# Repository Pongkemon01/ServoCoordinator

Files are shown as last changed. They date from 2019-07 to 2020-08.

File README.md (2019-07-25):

# Introduction 
TODO: Give a short introduction of your project. Let this section explain the objectives or the motivation behind this project. 

# Getting Started
TODO: Guide users through getting your code up and running on their own system. In this section you can talk about:
1.	Installation process
2.	Software dependencies
3.	Latest releases
4.	API references

# Build and Test
TODO: Describe and show how to build your code and run the tests. 

# Contribute
TODO: Explain how other users and developers can contribute to make your code better. 

If you want to learn more about creating good readme files then refer the following [guidelines](https://docs.microsoft.com/en-us/azure/devops/repos/git/create-a-readme?view=azure-devops). You can also seek inspiration from the below readme files:
- [ASP.NET Core](https://github.com/aspnet/Home)
- [Visual Studio Code](https://github.com/Microsoft/vscode)
- [Chakra Core](https://github.com/Microsoft/ChakraCore)

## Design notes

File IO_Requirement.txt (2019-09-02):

Note
===
Nuttx QEncoder module use TDTS = TCK_INT by leaving it as default (00).
Nuttx cannot operate in tickless mode because all required timers are used as encoder counters.
System clock configuration is in board.h as:
    - SYS_CLK         = 216MHz
    - USB_CLK         =  48MHz
    - APB1_CLK(PCLK1) =  54MHz (Timer1,8,9,10,11 operate at 108MHz (2x))
    - APB2_CLK(PCLK2) = 108MHz (Timer2,3,4,5,6,7,12,13,14 operate at 216MHz (2x))
STM32F7 has a dedicated timer all SysTick to periodically interrupt the system.  Nuttx uses this timer for system clock. (See stm32_timerisr.c)
SysTick input clock frequency is 27MHz (216MHz / 8).
The Nuttx default SysTick period is 10ms (100Hz). This value can be changed by defining CONFIG_USEC_PER_TICK in "defconfig" (undefined by default).
Starting additional drivers such as quadratic encoder must be manually include into "stm32_appinitialize.c".

Nuttx Kconfig modifications
===
The line 'default "coordinator" if ARCH_BOARD_COORDINATOR' must be add to configs/Kconfig.
The lines 
  if ARCH_BOARD_COORDINATOR
  source "configs/coordinator/Kconfig"
  endif
must be added to configs/Kconfig.
Also, the lines
   config ARCH_BOARD_COORDINATOR
        bool "PTTEP Coordinator(STM32F767ZI)"
        depends on ARCH_CHIP_STM32F767ZI
        select ARCH_HAVE_LEDS
        select ARCH_HAVE_BUTTONS
        select ARCH_HAVE_IRQBUTTONS
        ---help---
                This is the coordinator board for PTTEP project. It is based on
                STM32F767ZI built as Nucleo-144 board.
must be added to configs/Kconfig.

I/O requirement (Total 31 inputs and 42 outputs = 75 GPIOs)
===
Encoder+Home : 3-bit input per motor. Total 12+6 inputs.
Pulse+Direction : 2-bit output per motor. Total 12 outputs.
Control signal : 3-bit output (Servo_on, Alarm_reset, Deviation_clr) and 2-bit input (Alarm_status, Positioning_complete). Total 18 outputs + 12 inputs.
Emergency stop : 1-bit input
Status LED (Bi-color) : 2-bit output per LED. 1 LED per 1 motor. Total 12 outputs.
I2C for extension (Optional) : SCL SDA

I/O assignment (79 GPIO pins available)
===
CAUTION!!!: SB13 must be desoldered for PA1 (used by Ethernet) to be available
            JP7 must be removed to detached PB13 from Ethernet TXD
Optional: As Ethernet module is disabled, these SB can be desolderd to release some more IO pins:
    SB164 (PC1), SB160 (PA2), SB178 (PC4), SB181 (PC5), SB182 (PG13), SB183 (PG11)

- Fixed assignments
  ===
Encoders: PA0, PA1, PA15, PB3, PB4, PB5, PC6, PC7, PD12, PD13, PE9, PE11
  Enc0: GPIO_TIM1_CH1IN_2 (PE9) + GPIO_TIM1_CH2IN_2 (PE11)
  Enc1: GPIO_TIM2_CH1IN_2 (PA15) + GPIO_TIM2_CH2IN_2 (PB3)
  Enc2: GPIO_TIM3_CH1IN_2 (PB4) + GPIO_TIM3_CH2IN_2 (PB5)
  Enc3: GPIO_TIM4_CH1IN_2 (PD12) + GPIO_TIM4_CH2IN_2 (PD13)
  Enc4: GPIO_TIM5_CH1IN_1 (PA0) + GPIO_TIM5_CH2IN_1 (PA1)  (PA1 is not available on Zio connector. Must be wired to Morpho connector)
  Enc5: GPIO_TIM8_CH1IN_1 (PC6) + GPIO_TIM8_CH2IN_1 (PC7)

Motor pluse: PA6, PB8, PB9, PB15, PE5, PF9
  Motor0(Timer9): GPIO_TIM9_CH1OUT_2 (PE5)
  Motor1(Timer10): GPIO_TIM10_CH1OUT_1 (PB8)
  Motor2(Timer11): GPIO_TIM11_CH1OUT_1 (PB9)
  Motor3(Timer12): GPIO_TIM12_CH2OUT_1 (PB15) (Channel 1 out is not available on Nucleo-144. Thus, channel 2 is used.)
  Motor4(Timer13): GPIO_TIM13_CH1OUT_1 (PA6)
  Motor5(Timer14): GPIO_TIM14_CH1OUT_2 (PF9)

I2C(module 2)(Optional) : SCL=PB10, SDA=PB11
PA4(in), PA5(in) : Available for external interrupt pins

- Free assignments
  ===
  PA (3 pins) : 3, 4, 5
  PB (4 pins) : 0, 1, 2, 6, 12, 13 (JP7 must be removed)
  PC (8 pins) : 0, 2, 3, 8, 9, 10, 11, 12
  PD (13 pins): 0, 1, 2, 3, 4, 5, 6, 7, 11, 14, 15
  PE (12 pins): 0, 2, 3, 4, 6, 7, 8, 10, 12, 13, 14, 15
  PF (14 pins): 0, 1, 2, 3, 4, 5, 7, 8, 10, 12, 13, 14, 15
  PG (6 pins) : 0, 1, 2, 3, 9, 14

Emergency button : PA3
Home : PG0, PG1, PG2, PG3, PG9, PG14 (All PG)
Control signal (input){alrm_stat+pos_cmplt}: {PE0+PE8}, {PE2+PE10}, {PE3+PE12}, {PE4+PE13}, {PE6+PE14}, {PE7+PE15} (ALL PE)

Control signal (output){sv_on+alrm_res+dev_clr} : {PF0+PB0+PF7}, {PF1+PB1+PF8}, {PF2+PB2+PF10}, {PF3+PB6+PF12}, {PF4+PB12+PF13}, {PF5+PB13+PF14} (PB+PF)
Status LED : PD0, PD1, PD2, PD3, PD4, PD5, PD6, PD7, PD11, PD14, PD15, PF15
Direction : PC0, PC2, PC3, PC8, PC9, PC10

Pin direction
===
PA : Input
PB : Output
PC : Output
PD : Output
PE : Input
PF : Output
PG : Input

Unused I/O
===
PC11, PC12 (out)

Special function on GPIO after reset
===
The debug pins are in AF pull-up/pull-down after reset (Be careful):
PA15: JTDI in pull-up (input)
PB4: NJTRST in pull-up (input)
PB3: JTDO in floating state (output)

The following is CubeMX code to release PB3 and PB4 but it is better to avoid using these pins (especially PB3)
static void MX_GPIO_Init(void)
{
    GPIO_InitTypeDef GPIO_InitStruct;
    /* GPIO Ports Clock Enable */
    __HAL_RCC_GPIOB_CLK_ENABLE();
    __HAL_RCC_GPIOA_CLK_ENABLE();
    /*Configure GPIO pin Output Level */
    HAL_GPIO_WritePin(GPIOB, GPIO_PIN_4|GPIO_PIN_3, GPIO_PIN_RESET);
    /*Configure GPIO pins : PB4 PB3 */
    GPIO_InitStruct.Pin = GPIO_PIN_4|GPIO_PIN_3;
    GPIO_InitStruct.Mode = GPIO_MODE_OUTPUT_PP;
    GPIO_InitStruct.Pull = GPIO_NOPULL;
    GPIO_InitStruct.Speed = GPIO_SPEED_FREQ_LOW;
    HAL_GPIO_Init(GPIOB, &GPIO_InitStruct);
}

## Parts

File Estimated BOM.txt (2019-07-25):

Mouser
===
511-NUCLEO-F767ZI (Nucleo)	@THB731.40 x 1
SNO							@THB1558.20
SNOMkr						@THB922.20
ICM-20600(Mems+Gyro)		@THB103.67 x 1
TLP293-4					@THB40.0 x 10
DS26LV31TMX					@THB56.92 x 5
AM26LV32CDR					@THB43.25 x 5
IN-S85DATRG(LED)			@THB15.58 x 12
617-09663116501 (25pin con)	@THB193.98 x 6
538-39773-0002 (2pin con)	@THB35.30 x 10
CRCW08054K70FKEAC(R4.7k)	@THB0.731 x 100
CRCW0805330RFKEAC(R330)		@THB1.46 x 20
710-61302011121(pin header)	@THB31.01 x 10
437-8018300610001101(pin socket) @THB23.69 x 20

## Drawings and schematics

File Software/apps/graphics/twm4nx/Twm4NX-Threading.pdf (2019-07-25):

### Twm4x Main Thread

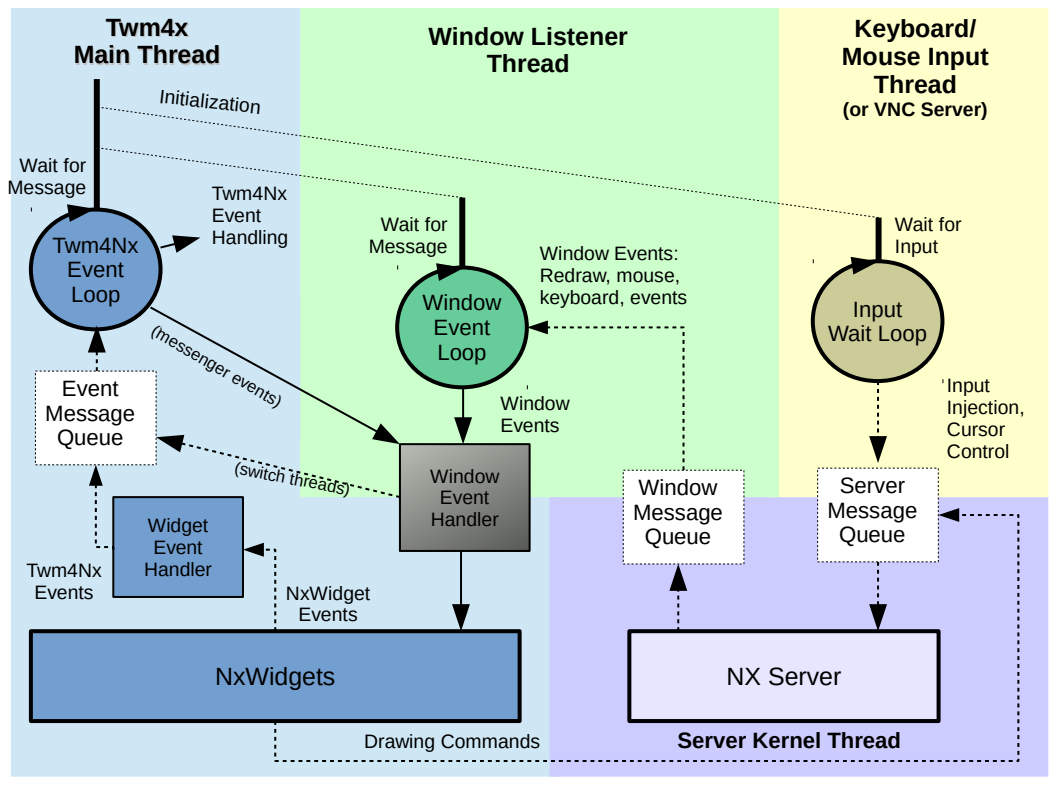
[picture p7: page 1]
Widget Event Handler; Twm4Nx Event Loop; Twm4Nx Event Handling; Initialization; Window Event Loop; Window Listener Thread; Input Wait Loop; Server Message Queue; Window Message Queue; Event Message Queue; NxWidgets; NX Server; Input Injection, Cursor Control; Window Events: Redraw, mouse, keyboard, events; Window Events; Drawing Commands; (switch threads); (messenger events); NxWidget Events; Twm4Nx Events; Window Event Handler; Wait for Input; Wait for Message

Keyboard/
Mouse Input
Thread
(or VNC Server)

Server Kernel Thread

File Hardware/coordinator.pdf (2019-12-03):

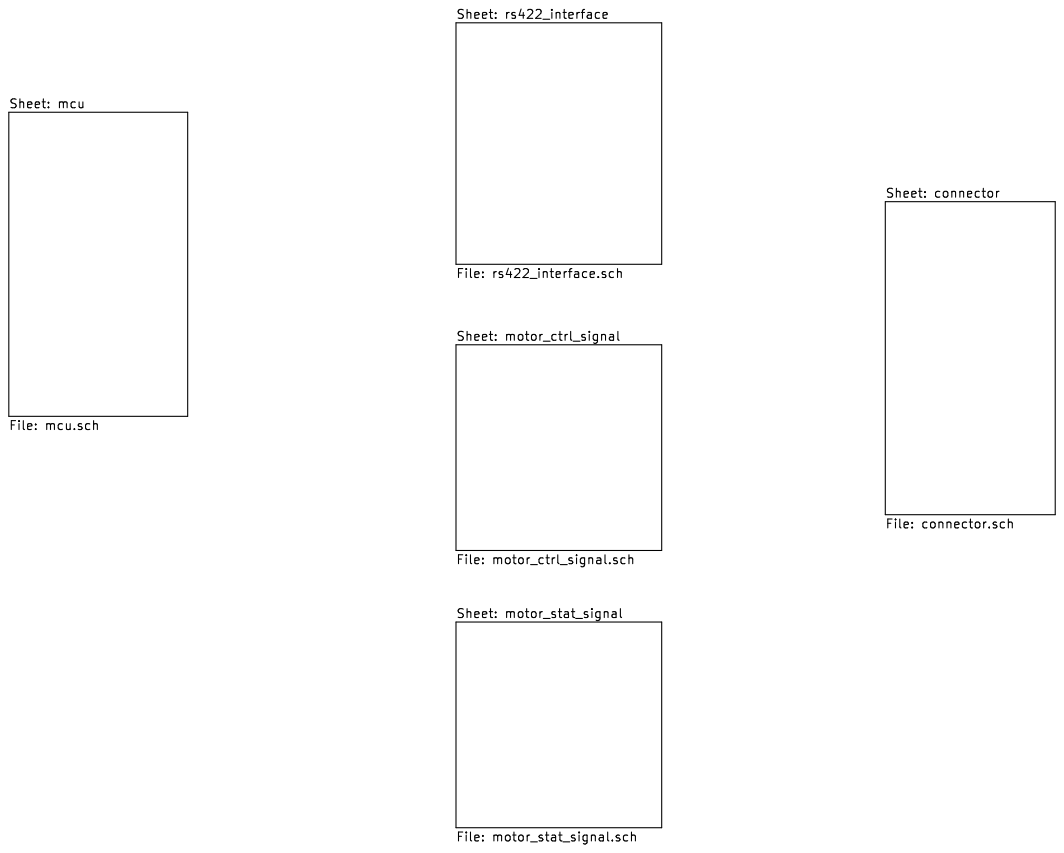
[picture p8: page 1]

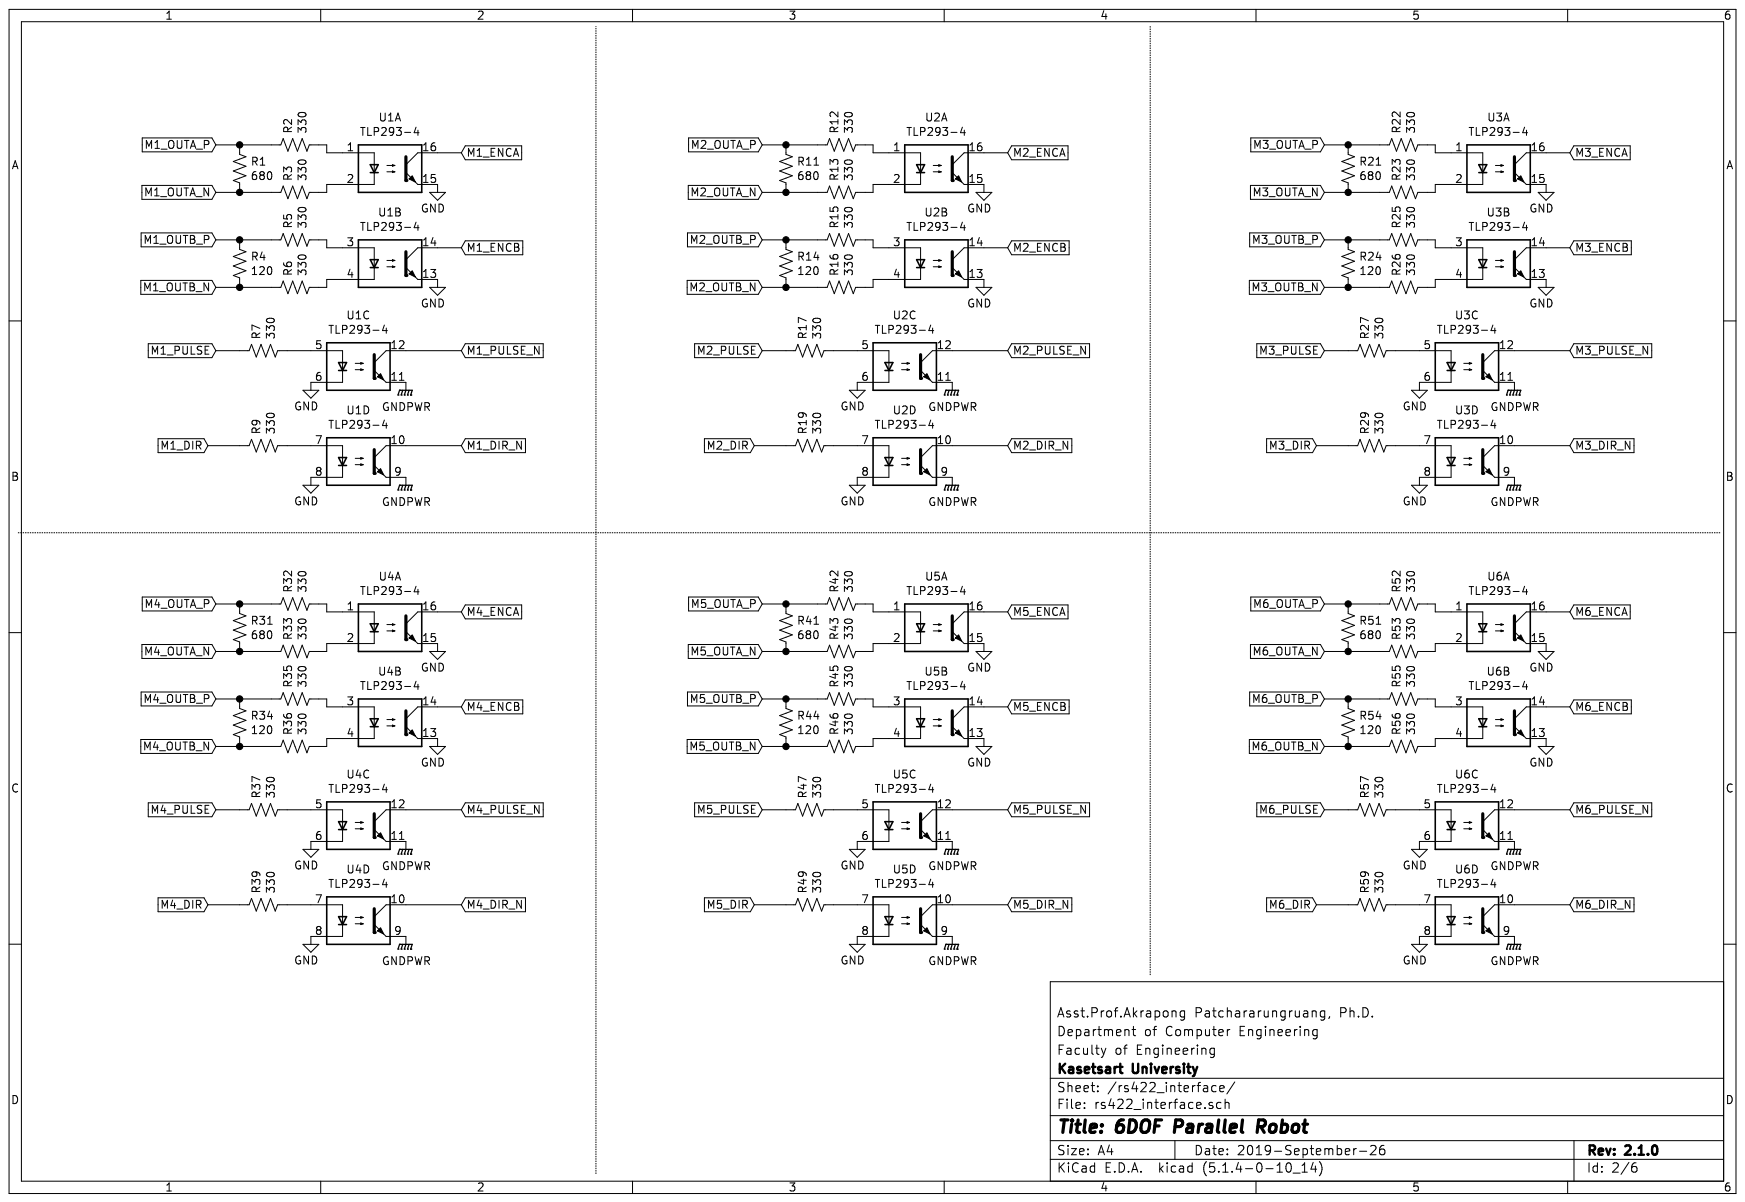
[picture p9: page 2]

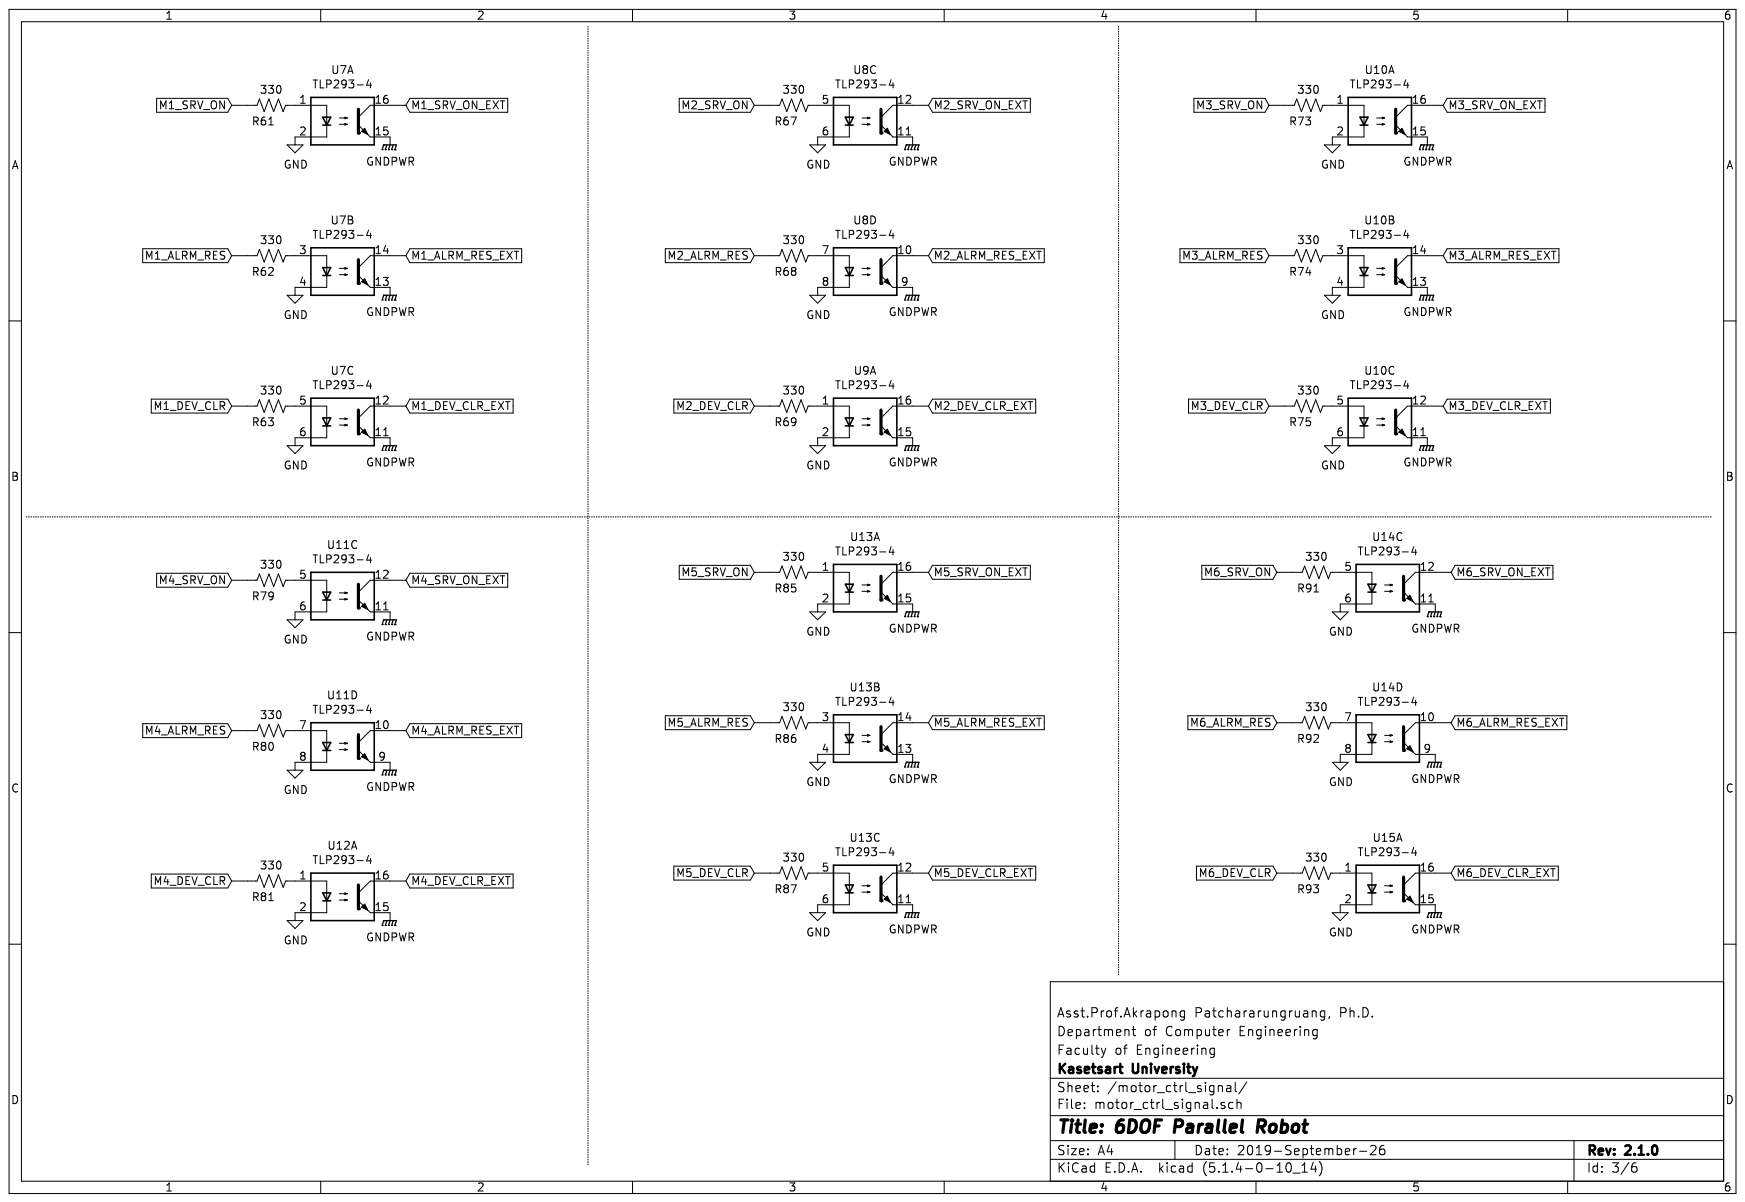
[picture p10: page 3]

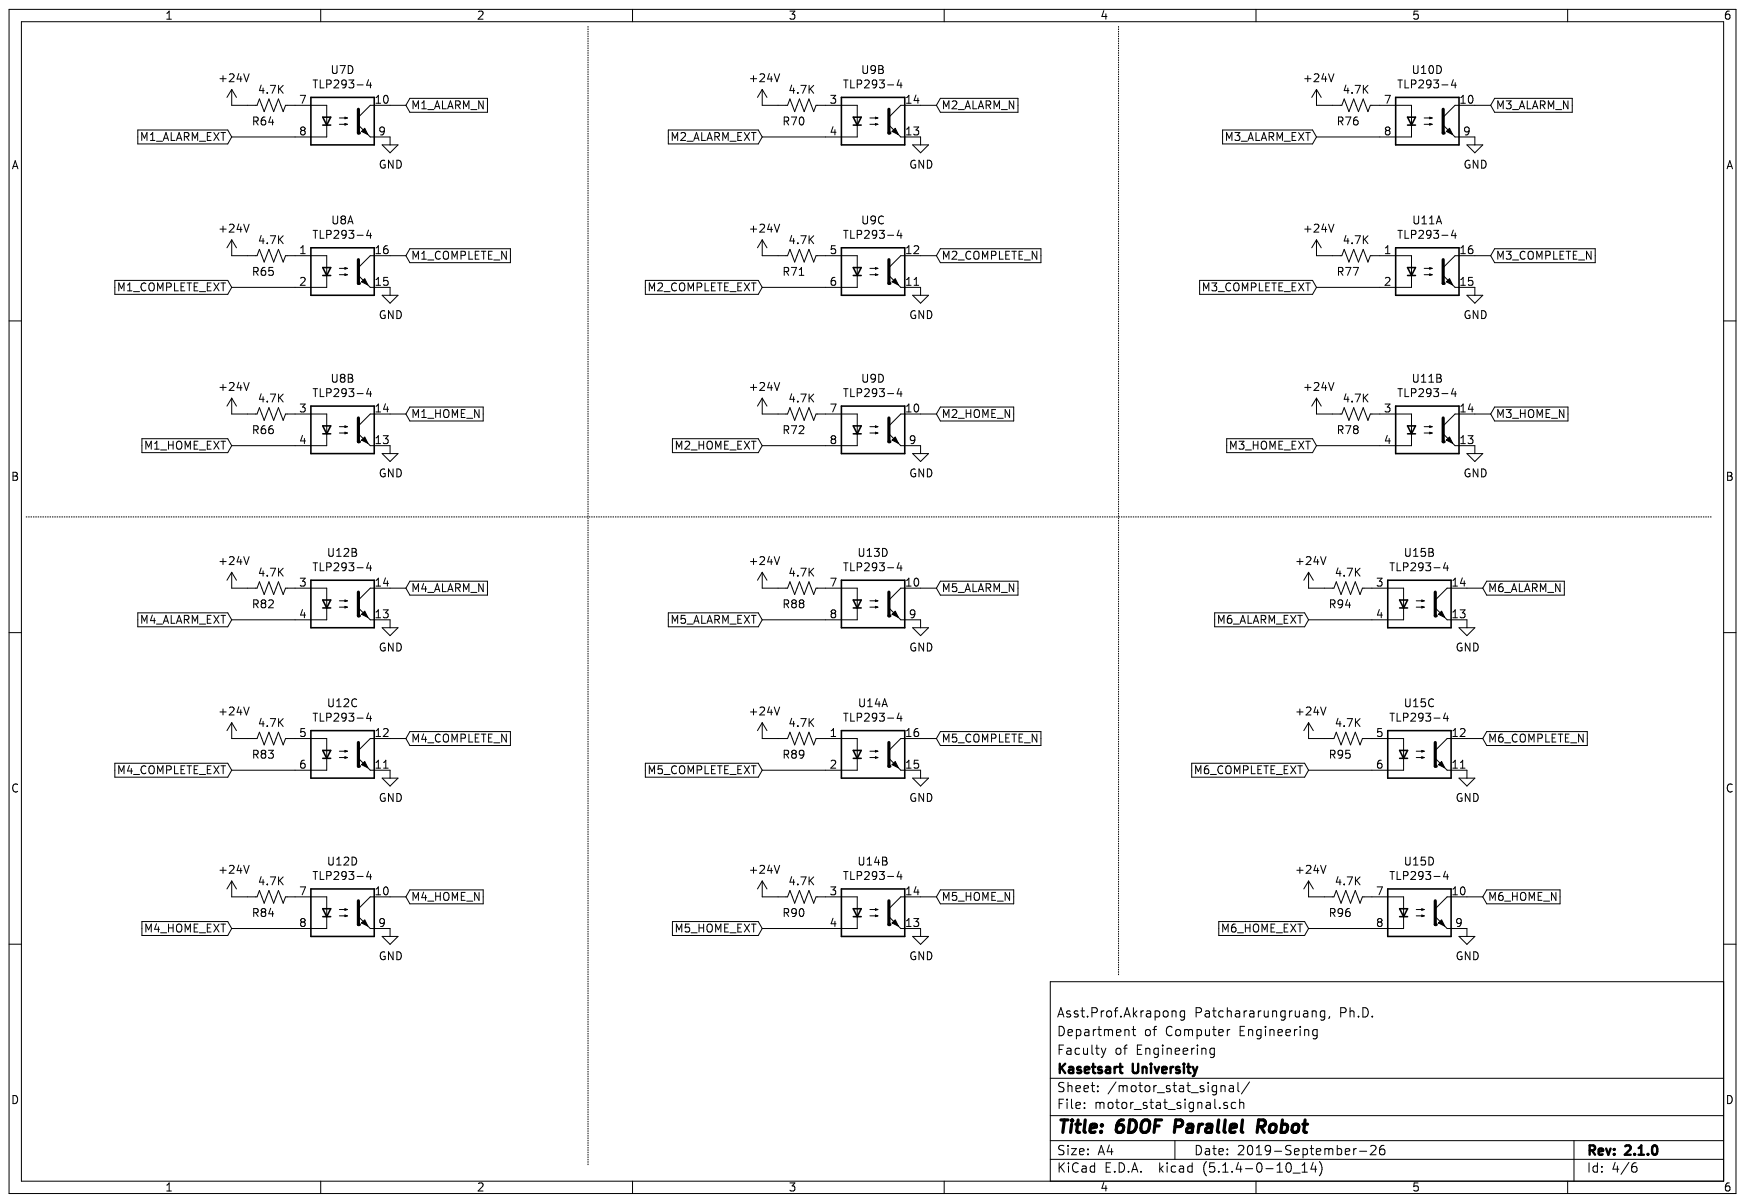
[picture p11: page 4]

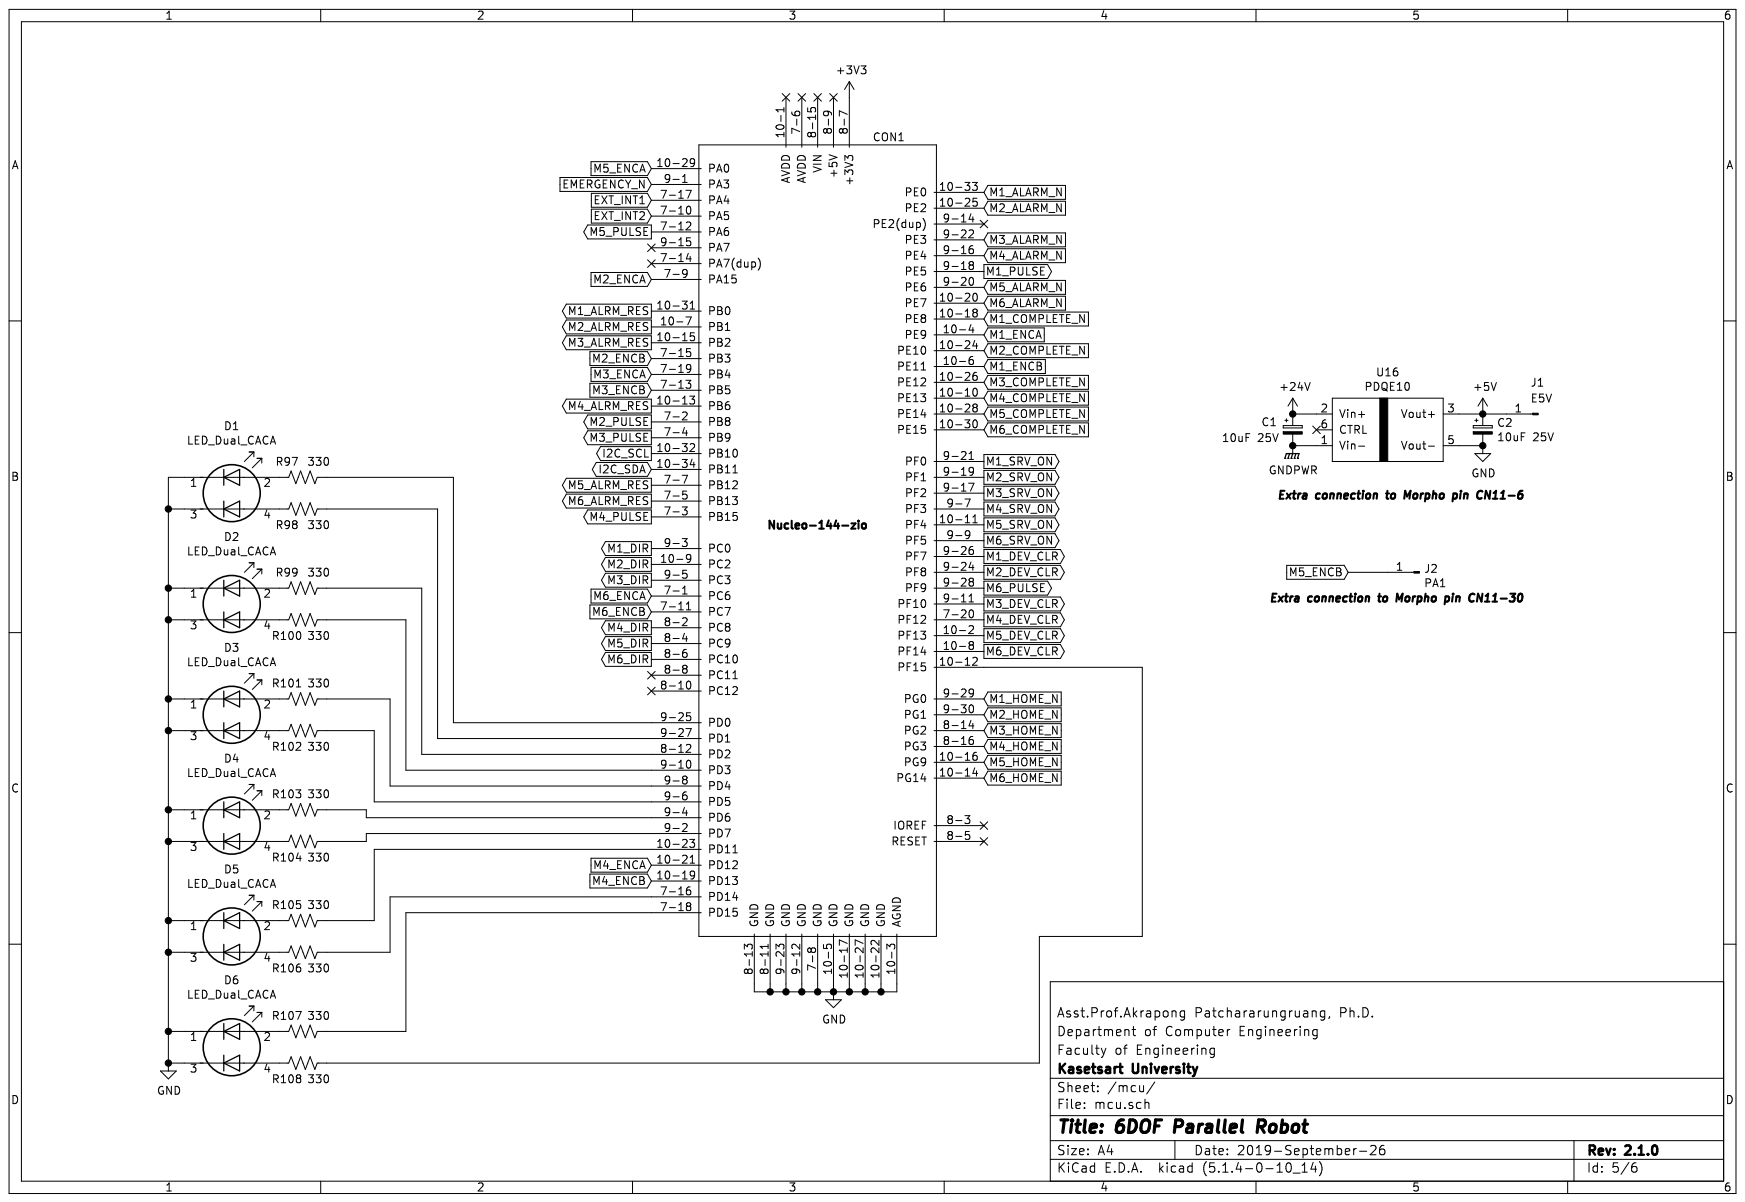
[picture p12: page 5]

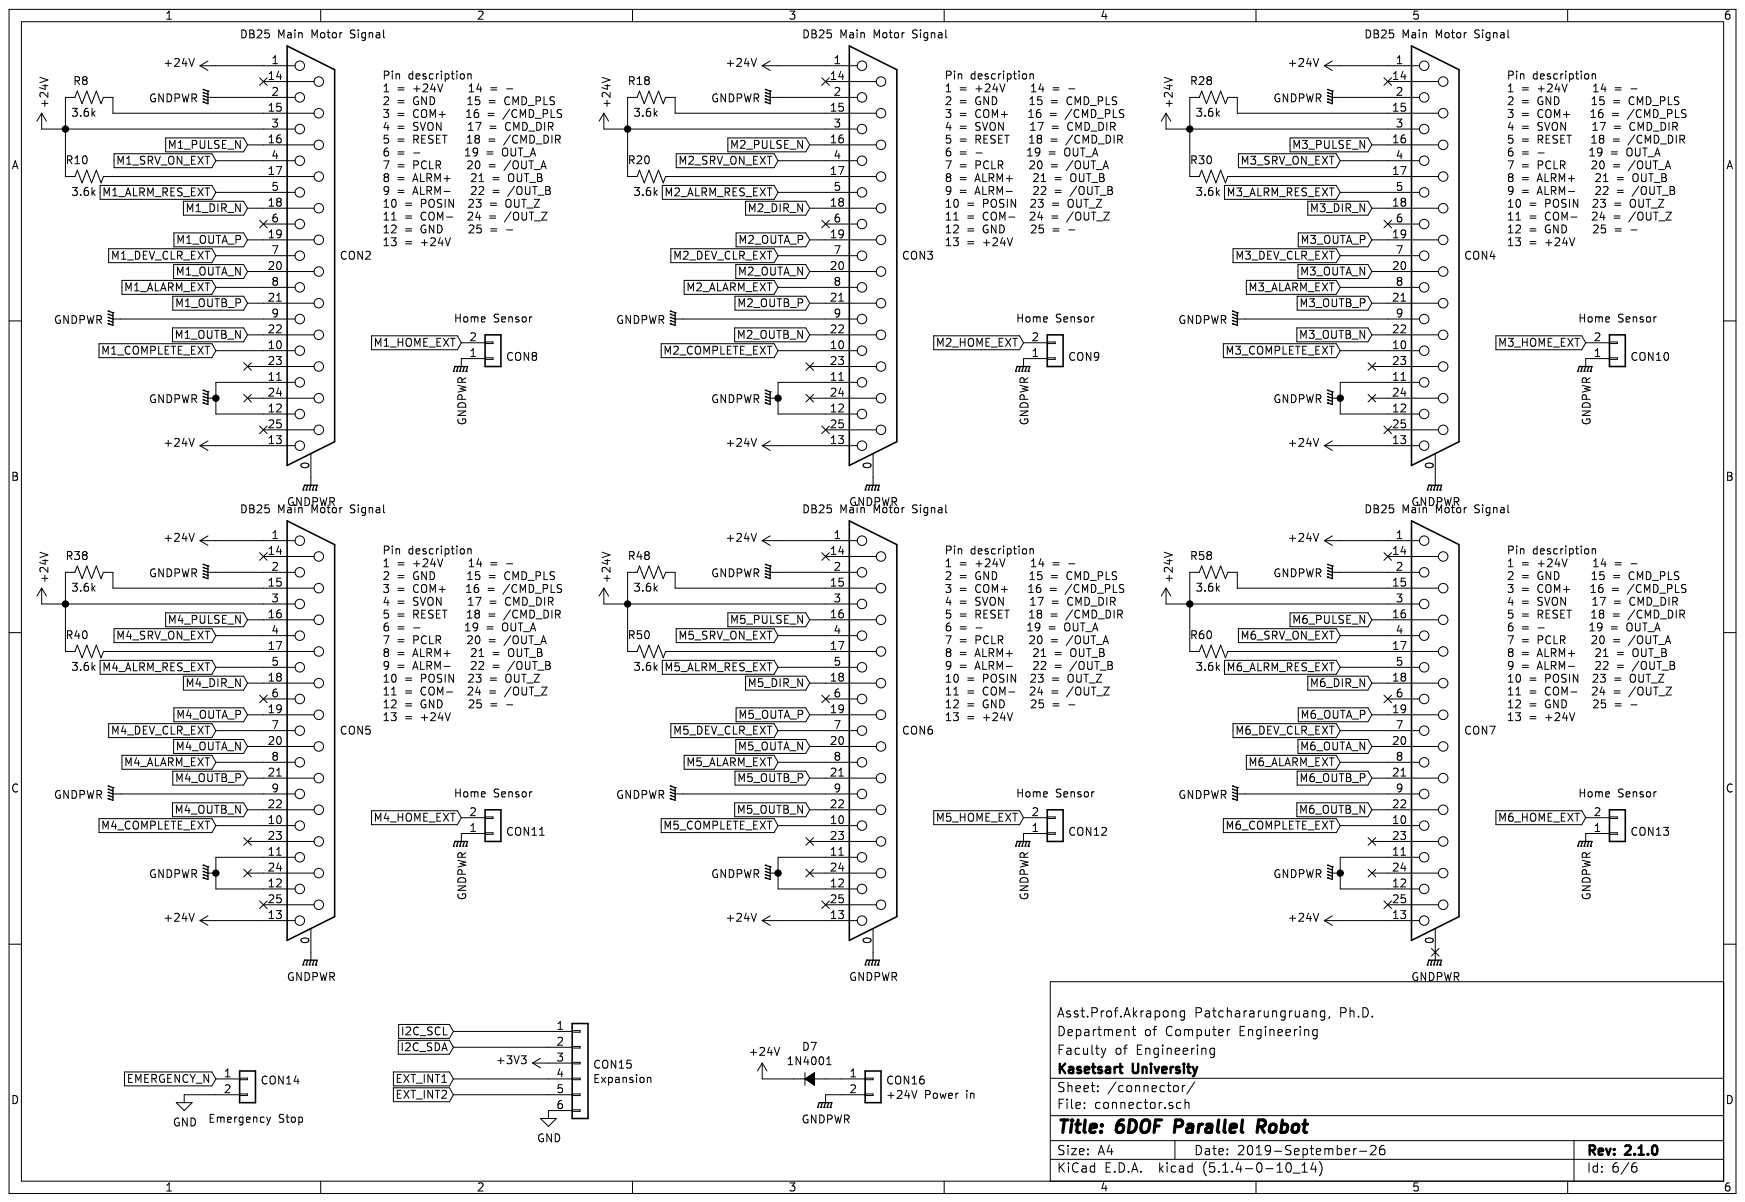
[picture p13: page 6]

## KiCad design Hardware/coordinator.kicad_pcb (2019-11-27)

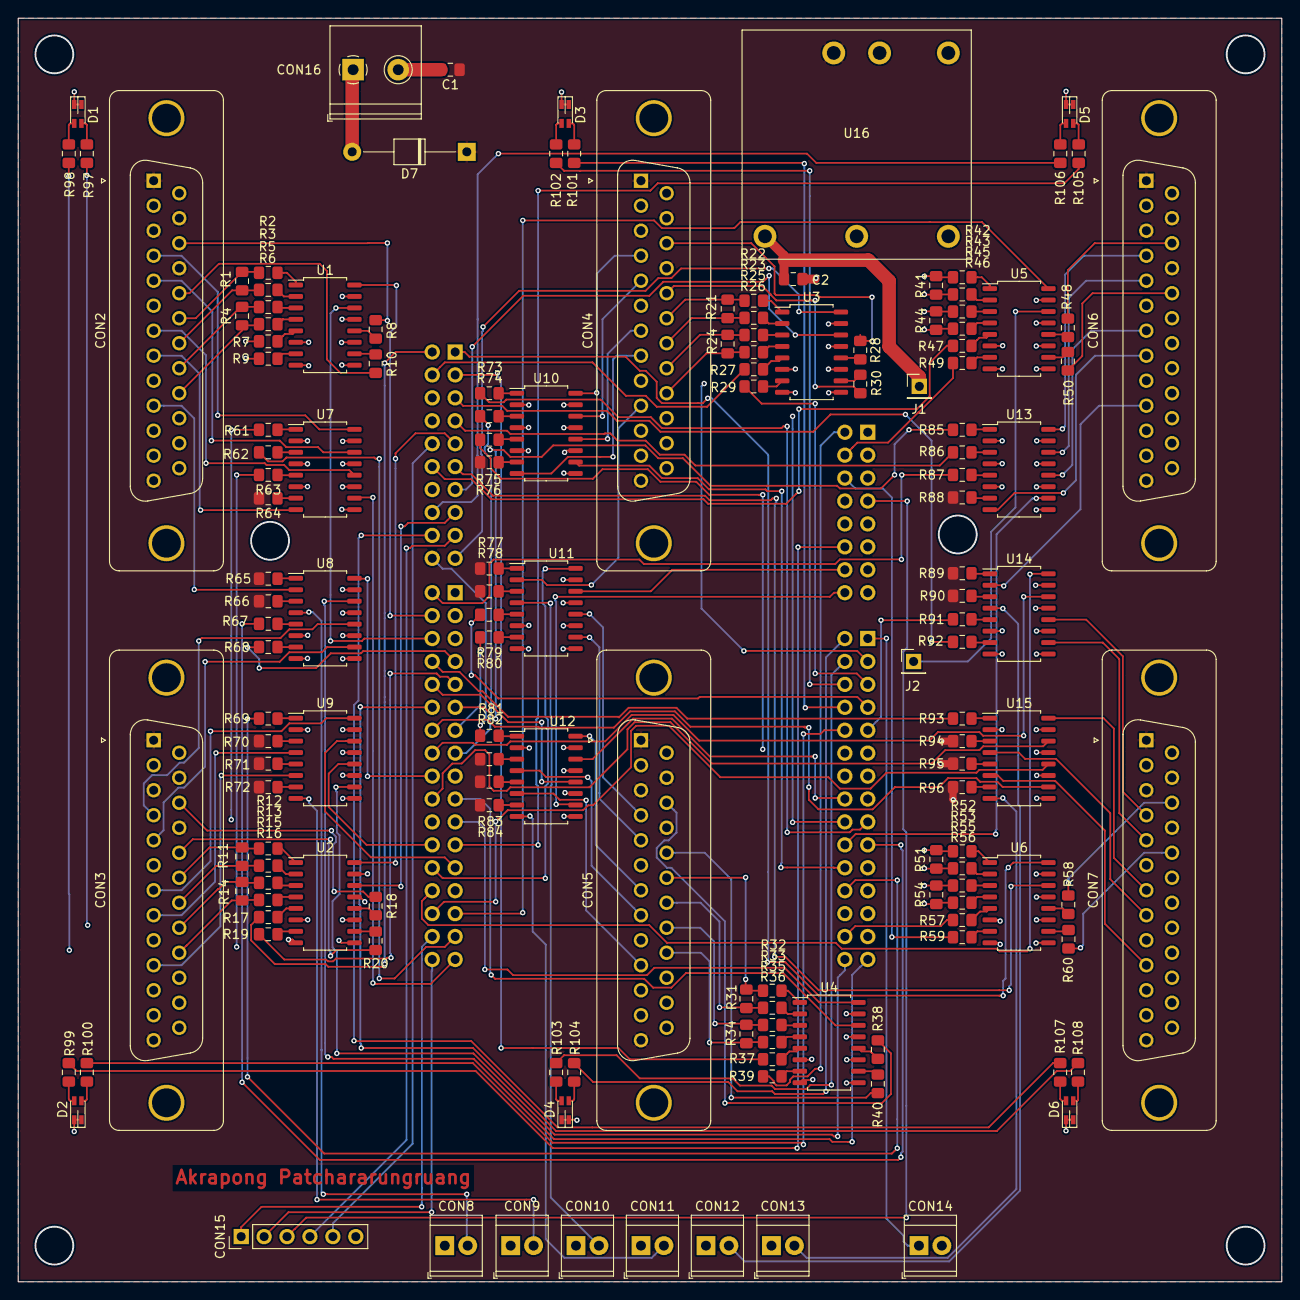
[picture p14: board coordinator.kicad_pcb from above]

Board: 4 copper layers, 140.0 x 140.0 mm, 151 parts (1 on the bottom side), 251 nets.

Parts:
C1, C2: 10uF 25V; C_0805_2012Metric_Pad1.15x1.40mm_HandSolder
CON1: Nucleo-144-zio
CON2, CON3, CON4, CON5, CON6, CON7: DB25 Main Motor Signal; DSUB-25_Female_Vertical_P2.77x2.84mm_MountingHoles
CON8, CON9, CON10, CON11, CON12, CON13: Home Sensor; TerminalBlock_TE_282834-2_1x02_P2.54mm_Horizontal
CON14: Emergency Stop; TerminalBlock_TE_282834-2_1x02_P2.54mm_Horizontal
CON15: Expansion; PinHeader_1x06_P2.54mm_Vertical
CON16: +24V Power in; TerminalBlock_Philmore_TB132_1x02_P5.00mm_Horizontal
D1, D2, D3, D4, D5, D6: LED_Dual_CACA; LED-Inlux-IN-S85DATRG
D7: 1N4001; D_T-1_P12.70mm_Horizontal
J1: E5V; PinHeader_1x01_P2.54mm_Vertical
J2: PA1; PinHeader_1x01_P2.54mm_Vertical
R1, R11, R21, R31, R41, R51: 680; R_0805_2012Metric_Pad1.15x1.40mm_HandSolder
R2, R3, R5, R6, R7, R9, R12, R13, R15, R16, R17, R19, R22, R23, R25, R26, R27, R29, R32, R33, R35, R36, R37, R39, R42, R43, R45, R46, R47, R49, R52, R53, R55, R56, R57, R59, R61, R62, R63, R67, R68, R69, R73, R74, R75, R79, R80, R81, R85, R86, R87, R91, R92, R93, R97, R98, R99, R100, R101, R102, R103, R104, R105, R106, R107, R108: 330; R_0805_2012Metric_Pad1.15x1.40mm_HandSolder
R4, R14, R24, R34, R44, R54: 120; R_0805_2012Metric_Pad1.15x1.40mm_HandSolder
R8, R10, R18, R20, R28, R30, R38, R40, R48, R50, R58, R60: 3.6k; R_0805_2012Metric_Pad1.15x1.40mm_HandSolder
R64, R65, R66, R70, R71, R72, R76, R77, R78, R82, R83, R84, R88, R89, R90, R94, R95, R96: 4.7K; R_0805_2012Metric_Pad1.15x1.40mm_HandSolder
U1, U2, U3, U4, U5, U6, U7, U8, U9, U10, U11, U12, U13, U14, U15: TLP292-4; SOIC-16_4.55x10.3mm_P1.27mm
U16: PDQE10

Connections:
+3V3: CON1.8-7, CON15.3
+5V: C2.1, J1.1, U16.3
+24V: C1.1, CON2.1, CON2.3, CON2.13, CON2.15, CON2.17, CON3.1, CON3.3, CON3.13, CON3.15, CON3.17, CON4.1, CON4.3, CON4.13, CON4.15, CON4.17, CON5.1, CON5.3, CON5.13, CON5.15, CON5.17, CON6.1, CON6.3, CON6.13, CON6.15, CON6.17, CON7.1, CON7.3, CON7.13, CON7.15, CON7.17, D7.1, R64.2, R65.2, R66.2, R70.2, R71.2, R72.2, R76.2, R77.2, R78.2, R82.2, R83.2, R84.2, R88.2, R89.2, R90.2, R94.2, R95.2, R96.2, U16.2
EMERGENCY_N: CON1.9-1, CON14.1
EXT_INT1: CON1.7-17, CON15.4
EXT_INT2: CON1.7-10, CON15.5
GND: C2.2, CON1.7-8, CON1.8-11, CON1.8-13, CON1.9-12, CON1.9-23, CON1.10-3, CON1.10-5, CON1.10-17, CON1.10-22, CON1.10-27, CON14.2, CON15.6, D1.1, D1.3, D2.1, D2.3, D3.1, D3.3, D4.1, D4.3, D5.1, D5.3, D6.1, D6.3, U1.6, U1.8, U1.13, U1.15, U2.6, U2.8, U2.13, U2.15, U3.6, U3.8, U3.13, U3.15, U4.6, U4.8, U4.13, U4.15, U5.6, U5.8, U5.13, U5.15, U6.6, U6.8, U6.13, U6.15, U7.2, U7.4, U7.6, U7.9, U8.6, U8.8, U8.13, U8.15, U9.2, U9.9, U9.11, U9.13, U10.2, U10.4, U10.6, U10.9, U11.6, U11.8, U11.13, U11.15, U12.2, U12.9, U12.11, U12.13, U13.2, U13.4, U13.6, U13.9, U14.6, U14.8, U14.13, U14.15, U15.2, U15.9, U15.11, U15.13, U16.5
GNDPWR: C1.2, CON2.0, CON2.2, CON2.9, CON2.11, CON2.12, CON3.0, CON3.2, CON3.9, CON3.11, CON3.12, CON4.0, CON4.2, CON4.9, CON4.11, CON4.12, CON5.0, CON5.2, CON5.9, CON5.11, CON5.12, CON6.0, CON6.2, CON6.9, CON6.11, CON6.12, CON7.0, CON7.2, CON7.9, CON7.11, CON7.12, CON8.1, CON9.1, CON10.1, CON11.1, CON12.1, CON13.1, CON16.2, U1.9, U1.11, U2.9, U2.11, U3.9, U3.11, U4.9, U4.11, U5.9, U5.11, U6.9, U6.11, U7.11, U7.13, U7.15, U8.9, U8.11, U9.15, U10.11, U10.13, U10.15, U11.9, U11.11, U12.15, U13.11, U13.13, U13.15, U14.9, U14.11, U15.15, U16.1
I2C_SCL: CON1.10-32, CON15.1
I2C_SDA: CON1.10-34, CON15.2
M1_ALARM_EXT: CON2.8, U7.8
M1_ALARM_N: CON1.10-33, U7.10
M1_ALRM_RES: CON1.10-31, R62.2
M1_ALRM_RES_EXT: CON2.5, U7.14
M1_COMPLETE_EXT: CON2.10, U8.2
M1_COMPLETE_N: CON1.10-18, U8.16
M1_DEV_CLR: CON1.9-26, R63.2
M1_DEV_CLR_EXT: CON2.7, U7.12
M1_DIR: CON1.9-3, R9.1
M1_DIR_N: CON2.18, R10.2
M1_ENCA: CON1.10-4, U1.16
M1_ENCB: CON1.10-6, U1.14
M1_HOME_EXT: CON8.2, U8.4
M1_HOME_N: CON1.9-29, U8.14
M1_OUTA_N: CON2.20, R1.2, R3.1
M1_OUTA_P: CON2.19, R1.1, R2.1
M1_OUTB_N: CON2.22, R4.2, R6.1
M1_OUTB_P: CON2.21, R4.1, R5.1
M1_PULSE: CON1.9-18, R7.1
M1_PULSE_N: CON2.16, R8.2
M1_SRV_ON: CON1.9-21, R61.2
M1_SRV_ON_EXT: CON2.4, U7.16
M2_ALARM_EXT: CON3.8, U9.4
M2_ALARM_N: CON1.10-25, U9.14
M2_ALRM_RES: CON1.10-7, R68.2
M2_ALRM_RES_EXT: CON3.5, U8.10
M2_COMPLETE_EXT: CON3.10, U9.6
M2_COMPLETE_N: CON1.10-24, U9.12
M2_DEV_CLR: CON1.9-24, R69.2
M2_DEV_CLR_EXT: CON3.7, U9.16
M2_DIR: CON1.10-9, R19.1
M2_DIR_N: CON3.18, R20.2
M2_ENCA: CON1.7-9, U2.16
M2_ENCB: CON1.7-15, U2.14
M2_HOME_EXT: CON9.2, U9.8
M2_HOME_N: CON1.9-30, U9.10
M2_OUTA_N: CON3.20, R11.2, R13.1
M2_OUTA_P: CON3.19, R11.1, R12.1
M2_OUTB_N: CON3.22, R14.2, R16.1
M2_OUTB_P: CON3.21, R14.1, R15.1
M2_PULSE: CON1.7-2, R17.1
M2_PULSE_N: CON3.16, R18.2
M2_SRV_ON: CON1.9-19, R67.2
M2_SRV_ON_EXT: CON3.4, U8.12
M3_ALARM_EXT: CON4.8, U10.8
M3_ALARM_N: CON1.9-22, U10.10
M3_ALRM_RES: CON1.10-15, R74.2
M3_ALRM_RES_EXT: CON4.5, U10.14
M3_COMPLETE_EXT: CON4.10, U11.2
M3_COMPLETE_N: CON1.10-26, U11.16
M3_DEV_CLR: CON1.9-11, R75.2
M3_DEV_CLR_EXT: CON4.7, U10.12
M3_DIR: CON1.9-5, R29.1
M3_DIR_N: CON4.18, R30.2
M3_ENCA: CON1.7-19, U3.16
M3_ENCB: CON1.7-13, U3.14
M3_HOME_EXT: CON10.2, U11.4
M3_HOME_N: CON1.8-14, U11.14
M3_OUTA_N: CON4.20, R21.2, R23.1
M3_OUTA_P: CON4.19, R21.1, R22.1
M3_OUTB_N: CON4.22, R24.2, R26.1
M3_OUTB_P: CON4.21, R24.1, R25.1
M3_PULSE: CON1.7-4, R27.1
M3_PULSE_N: CON4.16, R28.2
M3_SRV_ON: CON1.9-17, R73.2
M3_SRV_ON_EXT: CON4.4, U10.16
M4_ALARM_EXT: CON5.8, U12.4
M4_ALARM_N: CON1.9-16, U12.14
M4_ALRM_RES: CON1.10-13, R80.2
M4_ALRM_RES_EXT: CON5.5, U11.10
M4_COMPLETE_EXT: CON5.10, U12.6
M4_COMPLETE_N: CON1.10-10, U12.12
M4_DEV_CLR: CON1.7-20, R81.2
M4_DEV_CLR_EXT: CON5.7, U12.16
M4_DIR: CON1.8-2, R39.1
M4_DIR_N: CON5.18, R40.2
M4_ENCA: CON1.10-21, U4.16
M4_ENCB: CON1.10-19, U4.14
M4_HOME_EXT: CON11.2, U12.8
M4_HOME_N: CON1.8-16, U12.10
M4_OUTA_N: CON5.20, R31.2, R33.1
M4_OUTA_P: CON5.19, R31.1, R32.1
M4_OUTB_N: CON5.22, R34.2, R36.1
M4_OUTB_P: CON5.21, R34.1, R35.1
M4_PULSE: CON1.7-3, R37.1
M4_PULSE_N: CON5.16, R38.2
M4_SRV_ON: CON1.9-7, R79.2
M4_SRV_ON_EXT: CON5.4, U11.12
M5_ALARM_EXT: CON6.8, U13.8
M5_ALARM_N: CON1.9-20, U13.10
M5_ALRM_RES: CON1.7-7, R86.2
M5_ALRM_RES_EXT: CON6.5, U13.14
M5_COMPLETE_EXT: CON6.10, U14.2
M5_COMPLETE_N: CON1.10-28, U14.16
M5_DEV_CLR: CON1.10-2, R87.2
M5_DEV_CLR_EXT: CON6.7, U13.12
M5_DIR: CON1.8-4, R49.1
M5_DIR_N: CON6.18, R50.2
M5_ENCA: CON1.10-29, U5.16
M5_ENCB: J2.1, U5.14
M5_HOME_EXT: CON12.2, U14.4
M5_HOME_N: CON1.10-16, U14.14
M5_OUTA_N: CON6.20, R41.2, R43.1
M5_OUTA_P: CON6.19, R41.1, R42.1
M5_OUTB_N: CON6.22, R44.2, R46.1
M5_OUTB_P: CON6.21, R44.1, R45.1
M5_PULSE: CON1.7-12, R47.1
M5_PULSE_N: CON6.16, R48.2
M5_SRV_ON: CON1.10-11, R85.2
M5_SRV_ON_EXT: CON6.4, U13.16
M6_ALARM_EXT: CON7.8, U15.4
M6_ALARM_N: CON1.10-20, U15.14
M6_ALRM_RES: CON1.7-5, R92.2
M6_ALRM_RES_EXT: CON7.5, U14.10
M6_COMPLETE_EXT: CON7.10, U15.6
M6_COMPLETE_N: CON1.10-30, U15.12
M6_DEV_CLR: CON1.10-8, R93.2
M6_DEV_CLR_EXT: CON7.7, U15.16
M6_DIR: CON1.8-6, R59.1
M6_DIR_N: CON7.18, R60.2
M6_ENCA: CON1.7-1, U6.16
M6_ENCB: CON1.7-11, U6.14
M6_HOME_EXT: CON13.2, U15.8
M6_HOME_N: CON1.10-14, U15.10
M6_OUTA_N: CON7.20, R51.2, R53.1
M6_OUTA_P: CON7.19, R51.1, R52.1
M6_OUTB_N: CON7.22, R54.2, R56.1
M6_OUTB_P: CON7.21, R54.1, R55.1
M6_PULSE: CON1.9-28, R57.1
M6_PULSE_N: CON7.16, R58.2
M6_SRV_ON: CON1.9-9, R91.2
M6_SRV_ON_EXT: CON7.4, U14.12
unnamed: CON1.7-16, R106.1
unnamed: CON1.7-18, R107.1
unnamed: CON1.8-12, R99.1
unnamed: CON1.9-2, R104.1
unnamed: CON1.9-4, R103.1
unnamed: CON1.9-6, R102.1
unnamed: CON1.9-8, R101.1
unnamed: CON1.9-10, R100.1
unnamed: CON1.9-25, R97.1
unnamed: CON1.9-27, R98.1
unnamed: CON1.10-12, R108.1
unnamed: CON1.10-23, R105.1
unnamed: CON16.1, D7.2
unnamed: D1.2, R97.2
unnamed: D1.4, R98.2
unnamed: D2.2, R99.2
unnamed: D2.4, R100.2
unnamed: D3.2, R101.2
unnamed: D3.4, R102.2
unnamed: D4.2, R103.2
unnamed: D4.4, R104.2
unnamed: D5.2, R105.2
unnamed: D5.4, R106.2
unnamed: D6.2, R107.2
unnamed: D6.4, R108.2
unnamed: R2.2, U1.1
unnamed: R3.2, U1.2
unnamed: R5.2, U1.3
unnamed: R6.2, U1.4
unnamed: R7.2, U1.5
unnamed: R8.1, U1.12
unnamed: R9.2, U1.7
unnamed: R10.1, U1.10
unnamed: R12.2, U2.1
unnamed: R13.2, U2.2
unnamed: R15.2, U2.3
unnamed: R16.2, U2.4
unnamed: R17.2, U2.5
unnamed: R18.1, U2.12
unnamed: R19.2, U2.7
unnamed: R20.1, U2.10
unnamed: R22.2, U3.1
unnamed: R23.2, U3.2
unnamed: R25.2, U3.3
unnamed: R26.2, U3.4
unnamed: R27.2, U3.5
unnamed: R28.1, U3.12
unnamed: R29.2, U3.7
unnamed: R30.1, U3.10
unnamed: R32.2, U4.1
unnamed: R33.2, U4.2
unnamed: R35.2, U4.3
unnamed: R36.2, U4.4
unnamed: R37.2, U4.5
unnamed: R38.1, U4.12
unnamed: R39.2, U4.7
unnamed: R40.1, U4.10
unnamed: R42.2, U5.1
unnamed: R43.2, U5.2
unnamed: R45.2, U5.3
unnamed: R46.2, U5.4
unnamed: R47.2, U5.5
unnamed: R48.1, U5.12
unnamed: R49.2, U5.7
unnamed: R50.1, U5.10
unnamed: R52.2, U6.1
unnamed: R53.2, U6.2
unnamed: R55.2, U6.3
unnamed: R56.2, U6.4
unnamed: R57.2, U6.5
unnamed: R58.1, U6.12
unnamed: R59.2, U6.7
unnamed: R60.1, U6.10
unnamed: R61.1, U7.1
unnamed: R62.1, U7.3
unnamed: R63.1, U7.5
unnamed: R64.1, U7.7
unnamed: R65.1, U8.1
unnamed: R66.1, U8.3
unnamed: R67.1, U8.5
unnamed: R68.1, U8.7
unnamed: R69.1, U9.1
unnamed: R70.1, U9.3
unnamed: R71.1, U9.5
unnamed: R72.1, U9.7
unnamed: R73.1, U10.1
unnamed: R74.1, U10.3
unnamed: R75.1, U10.5
unnamed: R76.1, U10.7
unnamed: R77.1, U11.1
unnamed: R78.1, U11.3
unnamed: R79.1, U11.5
unnamed: R80.1, U11.7
unnamed: R81.1, U12.1
unnamed: R82.1, U12.3
unnamed: R83.1, U12.5
unnamed: R84.1, U12.7
unnamed: R85.1, U13.1
unnamed: R86.1, U13.3
unnamed: R87.1, U13.5
unnamed: R88.1, U13.7
unnamed: R89.1, U14.1
unnamed: R90.1, U14.3
unnamed: R91.1, U14.5
unnamed: R92.1, U14.7
unnamed: R93.1, U15.1
unnamed: R94.1, U15.3
unnamed: R95.1, U15.5
unnamed: R96.1, U15.7

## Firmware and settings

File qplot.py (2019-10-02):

'''
There are 3 ways to show the projection of the block
1) Euler Angles
2) Quaternion Angles
3) Input from raw data


Throughout the code, I have made comments on which lines to comment/uncomment 
depening on which method you choose. 

'''
#Importing modules/libraries 
from OpenGL.GL import *
from OpenGL.GLU import *
import pygame
import serial
from pygame.locals import *

from time import sleep
import math
from ctypes import c_float, c_int32, cast, byref, POINTER

#Initializing Variabes 
ax = ay = az = 0.0
t1=0
q0 = float(1.0)
q1 = float(0.0)
q2 = float(0.0)
q3 = float(0.0)
integralFBx = float(0.0)
integralFBy = float(0.0)
integralFBz = float(0.0)

#Initializing USB port connection
myserial = serial.Serial("/dev/tty.usbmodem142103", baudrate=115200, timeout=3.0)

def readlineCR(port):
    rv = ""
    while True:
        ch = (port.read()).decode("utf-8")
        rv += ch
        if ch=='\r' or ch=='\n' or ch=='':
            return rv

#Read Funtion 
def myRead(n):
    global myserial
    myBuffer=''
    while True:
        myBuffer = readlineCR(myserial)
        myBuffer = myBuffer.lstrip().rstrip()
        if len(myBuffer) <= 12:
            continue
        if ("Quaternion:" in myBuffer):  # Found the desired string
            # Split leading "UpdateData: - Quaternion:" from the rest
            quaternion = myBuffer.split(':')[2]
            quaternion = quaternion.lstrip()

            # Split the quaternion into elements
            q_elements = quaternion.split('+')
            if( len(q_elements ) != 4 ):
                continue    # Skip ill-format string

            # Trim all element spaces
            q_elements[0] = q_elements[0].lstrip().rstrip()
            q_elements[1] = q_elements[1].lstrip().rstrip()
            q_elements[2] = q_elements[2].lstrip().rstrip()
            q_elements[3] = q_elements[3].lstrip().rstrip()

            # Check the format and skip ill form
            if ( q_elements[1][len(q_elements[1]) - 1] != 'i' or q_elements[2][len(q_elements[2]) - 1] != 'j' or q_elements[3][len(q_elements[3]) - 1] != 'k' ):
               continue

            # Convert all elements into number
            w = float(q_elements[0])
            x = float(q_elements[1][:len(q_elements[1]) - 1])
            y = float(q_elements[2][:len(q_elements[2]) - 1])
            z = float(q_elements[3][:len(q_elements[3]) - 1])
            break   

    return w, x, y, z

def resize(width, height):
    if height == 0:
        height = 1
    glViewport(0, 0, width, height)
    glMatrixMode(GL_PROJECTION)
    glLoadIdentity()
    gluPerspective(45, 1.0 * width / height, 0.1, 100.0)
    glMatrixMode(GL_MODELVIEW)
    glLoadIdentity()

def init():
    glShadeModel(GL_SMOOTH)
    glClearColor(0.0, 0.0, 0.0, 0.0)
    glClearDepth(1.0)
    glEnable(GL_DEPTH_TEST)
    glDepthFunc(GL_LEQUAL)
    glHint(GL_PERSPECTIVE_CORRECTION_HINT, GL_NICEST)


#Funtion to display in GUI 
def drawtext(position, textstring):
    font = pygame.font.SysFont("Courier", 18, True)
    textsurface = font.render(textstring, True, (255, 255, 255, 255), (0, 0, 0, 255))
    textData = pygame.image.tostring(textsurface, "RGBA", True)
    glRasterPos3d(*position)
    glDrawPixels(textsurface.get_width(), textsurface.get_height(), GL_RGBA, GL_UNSIGNED_BYTE, textData)

#Function to display the block  
def draw():
    global ax,ay,az
    global rquad
    glClear(GL_COLOR_BUFFER_BIT | GL_DEPTH_BUFFER_BIT)

    glLoadIdentity()
    glTranslatef(0, 0.0, -7.0)

    osd_text = "pitch: " + str("{0:.2f}".format(ay)) + ", roll: " + str("{0:.2f}".format(ax))

    osd_line = osd_text + ", yaw: " + str("{0:.2f}".format(az))

    drawtext((-2, -2, 2), osd_line)

    # the way I'm holding the IMU board, X and Y axis are switched,with respect to the OpenGL coordinate system
    
    az=az+180  #Comment out if reading Euler Angle/Quaternion angles 
    glRotatef(az, 0.0, 1.0, 0.0)      # Yaw, rotate around y-axis

 
    glRotatef(ay, 1.0, 0.0, 0.0)          # Pitch, rotate around x-axis
    glRotatef(-1 * ax, 0.0, 0.0, 1.0)     # Roll, rotate around z-axis

    glBegin(GL_QUADS)
    glColor3f(1.0, 0.5, 0.0)
    glVertex3f(1.0, 0.2, -1.0)
    glVertex3f(-1.0, 0.2, -1.0)
    glVertex3f(-1.0, 0.2, 1.0)
    glVertex3f(1.0, 0.2, 1.0)

    glColor3f(1.0, 0.5, 0.0)
    glVertex3f(1.0, -0.2, 1.0)
    glVertex3f(-1.0, -0.2, 1.0)
    glVertex3f(-1.0, -0.2, -1.0)
    glVertex3f(1.0, -0.2, -1.0)

    glColor3f(1.0, 0.0, 0.0)
    glVertex3f(1.0, 0.2, 1.0)
    glVertex3f(-1.0, 0.2, 1.0)
    glVertex3f(-1.0, -0.2, 1.0)
    glVertex3f(1.0, -0.2, 1.0)

    glColor3f(1.0, 1.0, 0.0)
    glVertex3f(1.0, -0.2, -1.0)
    glVertex3f(-1.0, -0.2, -1.0)
    glVertex3f(-1.0, 0.2, -1.0)
    glVertex3f(1.0, 0.2, -1.0)

    glColor3f(0.0, 0.0, 1.0)
    glVertex3f(-1.0, 0.2, 1.0)
    glVertex3f(-1.0, 0.2, -1.0)
    glVertex3f(-1.0, -0.2, -1.0)
    glVertex3f(-1.0, -0.2, 1.0)

    glColor3f(1.0, 0.0, 1.0)
    glVertex3f(1.0, 0.2, -1.0)
    glVertex3f(1.0, 0.2, 1.0)
    glVertex3f(1.0, -0.2, 1.0)
    glVertex3f(1.0, -0.2, -1.0)
    glEnd()


#This function reads the Quaternion angle readings from the BnO055
def ReadQuaterion():
    global ax, ay, az
    w,x,y,z=myRead(2) #calls MyRead function to return after it is written

    #Turns the Quaternion readings into Euler Angles for projection
    ysqr = y*y
    t0 = +2.0 * (w * x + y*z)
    t1 = +1.0 - 2.0 * (x*x + ysqr)
    ax = (math.degrees(math.atan2(t0, t1)))
        
    t2 = +2.0 * (w*y - z*x)
    t2 =  1 if t2 > 1 else t2
    t2 = -1 if t2 < -1 else t2
    ay= math.degrees(math.asin(t2))
       
    t3 = +2.0 * (w * z + x*y)
    t4 = +1.0 - 2.0 * (ysqr + z*z)
    az=math.degrees(math.atan2(t3, t4))

def main():
    global ax,ay,az
    global yaw_mode
    global serial 
    video_flags = OPENGL | DOUBLEBUF
    pygame.init()
    screen = pygame.display.set_mode((640, 480), video_flags)
    pygame.display.set_caption("Press Esc to quit, z toggles yaw mode")
    resize(640, 480)
    frames = 0
    ticks = pygame.time.get_ticks()
    
    while 1:
        event = pygame.event.poll()
        if event.type == QUIT or (event.type == KEYDOWN and event.key == K_ESCAPE):
            break
        if event.type == KEYDOWN and event.key == K_z:
            yaw_mode = not yaw_mode
        
        pygame.display.flip()
        frames = frames + 1

        ReadQuaterion()
        draw()
           

if __name__ == '__main__': main()

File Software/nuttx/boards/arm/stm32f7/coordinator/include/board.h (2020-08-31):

/************************************************************************************
 * configs/coordinator/include/board.h
 *
 *   Copyright (C) 2016-2017 Gregory Nutt. All rights reserved.
 *   Authors: Gregory Nutt <gnutt@nuttx.org>
 *           Mark Olsson <post@markolsson.se>
 *           David Sidrane <david_s5@nscdg.com>
 *           Bob Feretich <bob.feretich@rafresearch.com>
 *
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
 * 1. Redistributions of source code must retain the above copyright
 *    notice, this list of conditions and the following disclaimer.
 * 2. Redistributions in binary form must reproduce the above copyright
 *    notice, this list of conditions and the following disclaimer in
 *    the documentation and/or other materials provided with the
 *    distribution.
 * 3. Neither the name NuttX nor the names of its contributors may be
 *    used to endorse or promote products derived from this software
 *    without specific prior written permission.
 *
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
 ************************************************************************************/

#ifndef __CONFIG_NUCLEO_144_INCLUDE_BOARD_H
#define __CONFIG_NUCLEO_144_INCLUDE_BOARD_H

/************************************************************************************
 * Included Files
 ************************************************************************************/

#include <nuttx/config.h>

#ifndef __ASSEMBLY__
# include <stdint.h>
#endif

#ifdef __KERNEL__
#include "stm32_rcc.h"
#ifdef CONFIG_STM32F7_SDMMC1
#  include "stm32_sdmmc.h"
#endif
#endif

/* Type conversion for logging */
typedef union
{
    float float_data;
    uint32_t uint32_data;
}Float_to_Uint32_t;

#define f2u32(x)    (((Float_to_Uint32_t)x).uint32_data)

/* #include "hardware/stm32_pinmap.h" */

/************************************************************************************
 * Pre-processor Definitions
 ************************************************************************************/

/* Clocking *************************************************************************/

/* The Nucleo-144  board provides the following clock sources:
 *
 *   MCO: 8 MHz from MCO output of ST-LINK is used as input clock
 *   X2:  32.768 KHz crystal for LSE
 *   X3:  HSE crystal oscillator (not provided)
 *
 * So we have these clock source available within the STM32
 *
 *   HSI: 16 MHz RC factory-trimmed
 *   LSI: 32 KHz RC
 *   HSE: 8 MHz from MCO output of ST-LINK
 *   LSE: 32.768 kHz
 */

#define STM32_BOARD_XTAL        8000000ul

#define STM32_HSI_FREQUENCY     16000000ul
#define STM32_LSI_FREQUENCY     32000
#define STM32_HSE_FREQUENCY     STM32_BOARD_XTAL
#define STM32_LSE_FREQUENCY     32768

/* Main PLL Configuration.
 *
 * PLL source is HSE = 8,000,000
 *
 * PLL_VCO = (STM32_HSE_FREQUENCY / PLLM) * PLLN
 * Subject to:
 *
 *     2 <= PLLM <= 63
 *   192 <= PLLN <= 432
 *   192 MHz <= PLL_VCO <= 432MHz
 *
 * SYSCLK  = PLL_VCO / PLLP
 * Subject to
 *
 *   PLLP = {2, 4, 6, 8}
 *   SYSCLK <= 216 MHz
 *
 * USB OTG FS, SDMMC and RNG Clock = PLL_VCO / PLLQ
 * Subject to
 *   The USB OTG FS requires a 48 MHz clock to work correctly. The SDMMC
 *   and the random number generator need a frequency lower than or equal
 *   to 48 MHz to work correctly.
 *
 * 2 <= PLLQ <= 15
 */

/* Highest SYSCLK with USB OTG FS clock = 48 MHz
 *
 * PLL_VCO = (8,000,000 / 4) * 216 = 432 MHz
 * SYSCLK  = 432 MHz / 2 = 216 MHz
 * USB OTG FS, SDMMC and RNG Clock = 432 MHz / 9 = 48 MHz
 */

#define STM32_PLLCFG_PLLM       RCC_PLLCFG_PLLM(4)
#define STM32_PLLCFG_PLLN       RCC_PLLCFG_PLLN(216)
#define STM32_PLLCFG_PLLP       RCC_PLLCFG_PLLP_2
#define STM32_PLLCFG_PLLQ       RCC_PLLCFG_PLLQ(9)

#define STM32_VCO_FREQUENCY     ((STM32_HSE_FREQUENCY / 4) * 216)
#define STM32_SYSCLK_FREQUENCY  (STM32_VCO_FREQUENCY / 2)
#define STM32_OTGFS_FREQUENCY   (STM32_VCO_FREQUENCY / 9)

/* Configure factors for  PLLSAI clock */

#define CONFIG_STM32F7_PLLSAI 1
#define STM32_RCC_PLLSAICFGR_PLLSAIN    RCC_PLLSAICFGR_PLLSAIN(192)
#define STM32_RCC_PLLSAICFGR_PLLSAIP    RCC_PLLSAICFGR_PLLSAIP(8)
#define STM32_RCC_PLLSAICFGR_PLLSAIQ    RCC_PLLSAICFGR_PLLSAIQ(4)
#define STM32_RCC_PLLSAICFGR_PLLSAIR    RCC_PLLSAICFGR_PLLSAIR(2)

/* Configure Dedicated Clock Configuration Register */

#define STM32_RCC_DCKCFGR1_PLLI2SDIVQ  RCC_DCKCFGR1_PLLI2SDIVQ(1)
#define STM32_RCC_DCKCFGR1_PLLSAIDIVQ  RCC_DCKCFGR1_PLLSAIDIVQ(1)
#define STM32_RCC_DCKCFGR1_PLLSAIDIVR  RCC_DCKCFGR1_PLLSAIDIVR(0)
#define STM32_RCC_DCKCFGR1_SAI1SRC     RCC_DCKCFGR1_SAI1SEL(0)
#define STM32_RCC_DCKCFGR1_SAI2SRC     RCC_DCKCFGR1_SAI2SEL(0)
#define STM32_RCC_DCKCFGR1_TIMPRESRC   0
#define STM32_RCC_DCKCFGR1_DFSDM1SRC   0
#define STM32_RCC_DCKCFGR1_ADFSDM1SRC  0

/* Configure factors for  PLLI2S clock */

#define CONFIG_STM32F7_PLLI2S 1
#define STM32_RCC_PLLI2SCFGR_PLLI2SN   RCC_PLLI2SCFGR_PLLI2SN(192)
#define STM32_RCC_PLLI2SCFGR_PLLI2SP   RCC_PLLI2SCFGR_PLLI2SP(2)
#define STM32_RCC_PLLI2SCFGR_PLLI2SQ   RCC_PLLI2SCFGR_PLLI2SQ(2)
#define STM32_RCC_PLLI2SCFGR_PLLI2SR   RCC_PLLI2SCFGR_PLLI2SR(2)
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

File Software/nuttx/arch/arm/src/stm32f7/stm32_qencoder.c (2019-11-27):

/************************************************************************************
 * arch/arm/src/stm32f7/stm32_qencoder.c
 *
 *   Copyright (C) 2018 Gregory Nutt. All rights reserved.
 *   Authors: Gregory Nutt <gnutt@nuttx.org>
 *            Diego Sanchez <dsanchez@nx-engineering.com>
 *
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
 * 1. Redistributions of source code must retain the above copyright
 *    notice, this list of conditions and the following disclaimer.
 * 2. Redistributions in binary form must reproduce the above copyright
 *    notice, this list of conditions and the following disclaimer in
 *    the documentation and/or other materials provided with the
 *    distribution.
 * 3. Neither the name NuttX nor the names of its contributors may be
 *    used to endorse or promote products derived from this software
 *    without specific prior written permission.
 *
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
 ************************************************************************************/

/************************************************************************************
 * Included Files
 ************************************************************************************/

#include <nuttx/config.h>

#include <stdint.h>
#include <assert.h>
#include <errno.h>
#include <debug.h>

#include <nuttx/arch.h>
#include <nuttx/irq.h>
#include <nuttx/sensors/qencoder.h>

#include <arch/board/board.h>

#include "chip.h"
#include "up_internal.h"
#include "up_arch.h"

#include "stm32_gpio.h"
#include "stm32_tim.h"
#include "stm32_qencoder.h"

#ifdef CONFIG_SENSORS_QENCODER

/************************************************************************************
 * Pre-processor Definitions
 ************************************************************************************/

/* Timers ***************************************************************************/

#undef HAVE_32BIT_TIMERS
#undef HAVE_16BIT_TIMERS

/* On the F7 series, TIM2 and TIM5 are 32-bit.  All of the rest are 16-bit */

/* If TIM2 or TIM5 are enabled, then we have 32-bit timers */

#if defined(CONFIG_STM32F7_TIM2_QE) || defined(CONFIG_STM32F7_TIM5_QE)
#  define HAVE_32BIT_TIMERS   1
#endif

/* If TIM1,3,4, or 8 are enabled, then we have 16-bit timers */

#if defined(CONFIG_STM32F7_TIM1_QE) || defined(CONFIG_STM32F7_TIM3_QE) || \
    defined(CONFIG_STM32F7_TIM4_QE) || defined(CONFIG_STM32F7_TIM8_QE)
#  define HAVE_16BIT_TIMERS   1
#endif

/* The width in bits of each timer */

#define TIM1_BITWIDTH         16
#define TIM2_BITWIDTH         32
#define TIM3_BITWIDTH         16
#define TIM4_BITWIDTH         16
#define TIM5_BITWIDTH         32
#define TIM8_BITWIDTH         16

/* Do we need to support mixed 16- and 32-bit timers */

#undef HAVE_MIXEDWIDTH_TIMERS
#if defined(HAVE_16BIT_TIMERS) && defined(HAVE_32BIT_TIMERS)
#  define HAVE_MIXEDWIDTH_TIMERS 1
#endif

/* Input filter *********************************************************************/

#ifdef CONFIG_STM32F7_QENCODER_FILTER
#  if defined(CONFIG_STM32F7_QENCODER_SAMPLE_FDTS)
#    if defined(CONFIG_STM32F7_QENCODER_SAMPLE_EVENT_1)
#      define STM32_QENCODER_ICF GTIM_CCMR_ICF_NOFILT
#    endif
#  elif defined(CONFIG_STM32F7_QENCODER_SAMPLE_CKINT)
#    if defined(CONFIG_STM32F7_QENCODER_SAMPLE_EVENT_2)
#      define STM32_QENCODER_ICF GTIM_CCMR_ICF_FCKINT2
#    elif defined(CONFIG_STM32F7_QENCODER_SAMPLE_EVENT_4)
#      define STM32_QENCODER_ICF GTIM_CCMR_ICF_FCKINT4
#    elif defined(CONFIG_STM32F7_QENCODER_SAMPLE_EVENT_8)
#      define STM32_QENCODER_ICF GTIM_CCMR_ICF_FCKINT8
#    endif
#  elif defined(CONFIG_STM32F7_QENCODER_SAMPLE_FDTS_2)
#    if defined(CONFIG_STM32F7_QENCODER_SAMPLE_EVENT_6)
#      define STM32_QENCODER_ICF GTIM_CCMR_ICF_FDTSd26
#    elif defined(CONFIG_STM32F7_QENCODER_SAMPLE_EVENT_8)
#      define STM32_QENCODER_ICF GTIM_CCMR_ICF_FDTSd28
#    endif
#  elif defined(CONFIG_STM32F7_QENCODER_SAMPLE_FDTS_4)
#    if defined(CONFIG_STM32F7_QENCODER_SAMPLE_EVENT_6)
#      define STM32_QENCODER_ICF GTIM_CCMR_ICF_FDTSd46
#    elif defined(CONFIG_STM32F7_QENCODER_SAMPLE_EVENT_8)
#      define STM32_QENCODER_ICF GTIM_CCMR_ICF_FDTSd48
#    endif
#  elif defined(CONFIG_STM32F7_QENCODER_SAMPLE_FDTS_8)
#    if defined(CONFIG_STM32F7_QENCODER_SAMPLE_EVENT_6)
#      define STM32_QENCODER_ICF GTIM_CCMR_ICF_FDTSd86
#    elif defined(CONFIG_STM32F7_QENCODER_SAMPLE_EVENT_8)
#      define STM32_QENCODER_ICF GTIM_CCMR_ICF_FDTSd88
#    endif
#  elif defined(CONFIG_STM32F7_QENCODER_SAMPLE_FDTS_16)
#    if defined(CONFIG_STM32F7_QENCODER_SAMPLE_EVENT_5)
#      define STM32_QENCODER_ICF GTIM_CCMR_ICF_FDTSd165
#    elif defined(CONFIG_STM32F7_QENCODER_SAMPLE_EVENT_6)
#      define STM32_QENCODER_ICF GTIM_CCMR_ICF_FDTSd166
#    elif defined(CONFIG_STM32F7_QENCODER_SAMPLE_EVENT_8)
#      define STM32_QENCODER_ICF GTIM_CCMR_ICF_FDTSd168
#    endif
#  elif defined(CONFIG_STM32F7_QENCODER_SAMPLE_FDTS_32)
#    if defined(CONFIG_STM32F7_QENCODER_SAMPLE_EVENT_5)
#      define STM32_QENCODER_ICF GTIM_CCMR_ICF_FDTSd325
#    elif defined(CONFIG_STM32F7_QENCODER_SAMPLE_EVENT_6)
#      define STM32_QENCODER_ICF GTIM_CCMR_ICF_FDTSd326
#    elif defined(CONFIG_STM32F7_QENCODER_SAMPLE_EVENT_8)
#      define STM32_QENCODER_ICF GTIM_CCMR_ICF_FDTSd328
#    endif
#  endif

#  ifndef STM32_QENCODER_ICF
#    warning "Invalid encoder filter combination, filter disabled"
#  endif
#endif

#ifndef STM32_QENCODER_ICF
#  define STM32_QENCODER_ICF GTIM_CCMR_ICF_NOFILT
#endif

#define STM32_GPIO_INPUT_FLOAT (GPIO_INPUT | GPIO_FLOAT)

/* Debug ****************************************************************************/

/* Non-standard debug that may be enabled just for testing the quadrature encoder */

#ifndef CONFIG_DEBUG_FEATURES
#  undef CONFIG_DEBUG_SENSORS
#endif

#ifdef CONFIG_DEBUG_SENSORS
#  ifdef CONFIG_DEBUG_INFO
#    define qe_dumpgpio(p,m)    stm32_dumpgpio(p,m)
#  else
#    define qe_dumpgpio(p,m)
#  endif
#else
#  define qe_dumpgpio(p,m)
#endif

/************************************************************************************
 * Private Types
 ************************************************************************************/

/* Constant configuration structure that is retained in FLASH */

struct stm32_qeconfig_s
{
  uint8_t   timid;   /* Timer ID {1,2,3,4,5,8} */
  uint8_t   irq;     /* Timer update IRQ */
  uint8_t   polarity; /* Input polarity 0 = positive, 1 = negative */
#ifdef HAVE_MIXEDWIDTH_TIMERS
  uint8_t   width;   /* Timer width (16- or 32-bits) */
#endif
#ifdef CONFIG_STM32_STM32F10XX
  uint16_t  ti1cfg;  /* TI1 input pin configuration (16-bit encoding) */
  uint16_t  ti2cfg;  /* TI2 input pin configuration (16-bit encoding) */
#else
  uint32_t  ti1cfg;  /* TI1 input pin configuration (20-bit encoding) */
  uint32_t  ti2cfg;  /* TI2 input pin configuration (20-bit encoding) */
#endif
  uintptr_t regaddr; /* RCC clock enable register address */
  uint32_t  enable;  /* RCC clock enable bit */
  uint32_t  base;    /* Register base address */
  uint32_t  psc;     /* Timer input clock prescaler */
};
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

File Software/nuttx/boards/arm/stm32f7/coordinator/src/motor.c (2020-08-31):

/************************************************************************************
 * configs/coordinator/motor.c
 *
 *   Copyright (C) 2019 Uros Platise. All rights reserved.
 *   Author: Akrapong Patchararungruang (akrapong.p@ku.th)
 *
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
 * 1. Redistributions of source code must retain the above copyright
 *    notice, this list of conditions and the following disclaimer.
 * 2. Redistributions in binary form must reproduce the above copyright
 *    notice, this list of conditions and the following disclaimer in
 *    the documentation and/or other materials provided with the
 *    distribution.
 * 3. Neither the name NuttX nor the names of its contributors may be
 *    used to endorse or promote products derived from this software
 *    without specific prior written permission.
 *
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
 ************************************************************************************/

/************************************************************************************
 * Driver for motor. There are 6 motors in this system. Each motor utilizes the same
 * driver module. Each motor is drived by a NIDEC-SANKYO S-FLAG servo driver.
 * The driver operates in "position mode" with its interal feedback loop.
 * External motor control should be perform in open-loop fashion because adding more
 * control loop is considered redundant and makes the overall system unstable through
 * out the operation load. The control signals used to interface with the S-FLAG are:
 *   - CMD_PLS - (output to driver) Pulse command to specify the rotational distance
 *   - CMD_DIR - (output to driver) Rotational direction (clock-wise/counter clock-wise)
 *   - SVON - (output to driver) Enable motor driver
 *   - RESET - (output to driver) Pulse to reset errors
 *   - PCLR - (output to driver) Deviation counter clear
 *   - ALM - (input from driver) Alarm status
 *   - POSIN - (input from driver) Positioning completed
 * All above signals except CMD_PLS are controlled directly from this driver via
 * GPIOs. The CMD_PLS signals are controlled separately by PFM driver, which is
 * an internal driver in the kernel space (See stm32_pfm.c and stm32_pfm.h).
 * Each motor also has 2 LEDs (Red and Green) to indicates the status as:
 *    - Red-on, Green-on - Motor is not ready or uninitialized
 *    - Red-off, Green-on - Motor is initialized and ready
 *    - Red-on, Green-off - Motor alarm
 *    - Red-off, Green-off - Driver is uninitailized
 ************************************************************************************/

/************************************************************************************
 * Included Files
 ************************************************************************************/

#include <nuttx/config.h>
#include <nuttx/arch.h>
#include <nuttx/irq.h>
#include <nuttx/kmalloc.h>
#include <nuttx/fs/fs.h>

#include <sys/types.h>
#include <stdio.h>
#include <stdint.h>
#include <stdbool.h>
#include <semaphore.h>
#include <errno.h>
#include <debug.h>
#include <time.h>

#include <arch/board/board.h>

#include "chip.h"
#include "up_internal.h"
#include "up_arch.h"
#include "stm32_gpio.h"
#include "stm32_pfm.h"
#include <arch/board/motor.h>

/************************************************************************************
 * Private Types
 ************************************************************************************/

/* Motor configuration structure */
struct motor_cfg_s
{
  uint32_t  motor_id;     /* PFM id of this motor */
  uint32_t  dir_pin;      /* Motor direction pin */
  uint32_t  srv_on_pin;   /* Motor enable pin */
  uint32_t  alrm_res_pin; /* Alarm reset pin */
  uint32_t  dev_clr_pin;  /* Counter-deviation clear pin */
  uint32_t  alrm_pin;     /* Motor alarm input pin */
  uint32_t  cmplt_pin;    /* Command complete input pin */
  uint32_t  led_red;      /* Red LED control pin */
  uint32_t  led_green;    /* Green LED control pin */
};

struct motor_priv_s
{
  FAR struct motor_cfg_s      *cfg;
  FAR struct stm32_pfm_dev_s  *pfm;
  volatile int32_t            step_count;
  volatile motor_state_t      state;
  volatile bool               is_cw;  /* Is negative direction? */
  volatile bool               is_start; /* The motor has been started without any stop command */
};

/************************************************************************************
 * Private Data
 ************************************************************************************/

// GPIO assignment for each motor signal
struct motor_cfg_s motor_cfg[6] = 
{

{
  .motor_id     = 0,
  .dir_pin      = GPIO_MTR1_DIRECTION,
  .srv_on_pin   = GPIO_MTR1_SVON,
  .alrm_res_pin = GPIO_MTR1_ALRM_RES,
  .dev_clr_pin  = GPIO_MTR1_DEV_CLR,
  .alrm_pin     = GPIO_MTR1_ALRM,
  .cmplt_pin    = GPIO_MTR1_CMPLT,
  .led_red      = GPIO_MTR1_LED_RED,
  .led_green    = GPIO_MTR1_LED_GRN
},

{
  .motor_id     = 1,
  .dir_pin      = GPIO_MTR2_DIRECTION,
  .srv_on_pin   = GPIO_MTR2_SVON,
  .alrm_res_pin = GPIO_MTR2_ALRM_RES,
  .dev_clr_pin  = GPIO_MTR2_DEV_CLR,
  .alrm_pin     = GPIO_MTR2_ALRM,
  .cmplt_pin    = GPIO_MTR2_CMPLT,
  .led_red      = GPIO_MTR2_LED_RED,
  .led_green    = GPIO_MTR2_LED_GRN
},

{
  .motor_id     = 2,
  .dir_pin      = GPIO_MTR3_DIRECTION,
  .srv_on_pin   = GPIO_MTR3_SVON,
  .alrm_res_pin = GPIO_MTR3_ALRM_RES,
  .dev_clr_pin  = GPIO_MTR3_DEV_CLR,
  .alrm_pin     = GPIO_MTR3_ALRM,
  .cmplt_pin    = GPIO_MTR3_CMPLT,
  .led_red      = GPIO_MTR3_LED_RED,
  .led_green    = GPIO_MTR3_LED_GRN
},

{
  .motor_id     = 3,
  .dir_pin      = GPIO_MTR4_DIRECTION,
  .srv_on_pin   = GPIO_MTR4_SVON,
  .alrm_res_pin = GPIO_MTR4_ALRM_RES,
  .dev_clr_pin  = GPIO_MTR4_DEV_CLR,
  .alrm_pin     = GPIO_MTR4_ALRM,
  .cmplt_pin    = GPIO_MTR4_CMPLT,
  .led_red      = GPIO_MTR4_LED_RED,
  .led_green    = GPIO_MTR4_LED_GRN
},

{
  .motor_id     = 4,
  .dir_pin      = GPIO_MTR5_DIRECTION,
  .srv_on_pin   = GPIO_MTR5_SVON,
  .alrm_res_pin = GPIO_MTR5_ALRM_RES,
  .dev_clr_pin  = GPIO_MTR5_DEV_CLR,
  .alrm_pin     = GPIO_MTR5_ALRM,
  .cmplt_pin    = GPIO_MTR5_CMPLT,
  .led_red      = GPIO_MTR5_LED_RED,
  .led_green    = GPIO_MTR5_LED_GRN
},

{
  .motor_id     = 5,
  .dir_pin      = GPIO_MTR6_DIRECTION,
  .srv_on_pin   = GPIO_MTR6_SVON,
  .alrm_res_pin = GPIO_MTR6_ALRM_RES,
  .dev_clr_pin  = GPIO_MTR6_DEV_CLR,
  .alrm_pin     = GPIO_MTR6_ALRM,
  .cmplt_pin    = GPIO_MTR6_CMPLT,
  .led_red      = GPIO_MTR6_LED_RED,
  .led_green    = GPIO_MTR6_LED_GRN
}

};

// Motor internal data (including the previous defined GPIO configuration)
struct motor_priv_s motor_priv[6] =
{

{
  .cfg    = &(motor_cfg[0]),
  .pfm    = NULL,
  .step_count = 0L,
  .is_cw  = false,
  .is_start = false,
  .state  = MOTOR_UNINIT
},

{
  .cfg    = &(motor_cfg[1]),
  .pfm    = NULL,
  .step_count = 0L,
  .is_cw  = false,
  .is_start = false,
  .state  = MOTOR_UNINIT
},

{
  .cfg    = &(motor_cfg[2]),
  .pfm    = NULL,
  .step_count = 0L,
  .is_cw  = false,
  .is_start = false,
  .state  = MOTOR_UNINIT
},
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

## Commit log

2019-07-25 Squashed 'Software/nuttx/' content from commit 933e9e407b
    git-subtree-dir: Software/nuttx
    git-subtree-split: 933e9e407b55cec357d3e7daf558a105d2c7507d
    [armusbocd.cfg, atmel_same70_xplained.cfg, dk-tm4c129x.cfg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]
2019-09-02 First rough driver compilation for PTTEP show
    [connector.sch, coordinator.kicad_pcb, coordinator.sch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]
2019-09-02 Squashed 'Software/nuttx/' changes from 933e9e407b..100fe59ff2
    100fe59ff2 net/arp/arp.h: Remove an unused structure definition.
    85770966ff boards/Board.mk: Add support to pass dependency paths. boards/arm/cxd56xx/common/Makefile: Add correct dependency paths for board/ and src/ subdirectories.
    d596e56c3d net/local/local_conn.c: Removed un-ncessary memset(). Connection structure is allocated with kmm_zalloc() which will clear all memory.
    6266e067e9 net/: Re-order the content of all address-family socket 'connection' structures so that they begin with a comomon prologue. This permits better use of logic for different address family types.
    19e1db3f97 arch/arm/src/stm32/hardware/stm32_ad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
    [armusbocd.cfg, atmel_same70_xplained.cfg, dk-tm4c129x.cfg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]
2019-09-02 Squashed 'Software/apps/' changes from 44a8d7c80e..104d7f3716
    104d7f3716 Merged in masayuki2009/nuttx.apps/gs2200m_supports_SIOCGIFHWADDR (pull request #199)
    aa6d5106e7 Makefile: Added support for application-specific export target. Used by nuttx/tools/mkexport.sh.
    3a75edca20 Fix minor typo/copy-paste: 'will be use when'->'will be used when'
    ac61c18fcc Move apps/builtins/builtin_forindex.c to nuttx/libs/libc/builtin since it is required by kernel logic as well. Other changes account for movement of builtin.h from nuttx/include/nuttx/binfmt/built.h to nuttx/include/lib/builtin.h.
    839efa6669 Merged in david_alessio/apps/bugfix/i2ctool-dev-clobbers-slave-config (pull request #198)
    811086ff85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
2019-09-04 First finish of all drivers. Ready for application layer.
2019-09-04 Expose Timer7 to user-space.
2019-09-17 Add support for MPU9250 (Sparkfun break-out) in I2C mode at 100Hz sensor rate
2019-09-26 Freeze version 1 as the RS-422 interface cannot tolerate noise generated from the driver.
    [board.h, coordinator_actor.c, coordinator_token_parser.c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]
2019-10-02 Original commit of version 2. The firmware is similar to version 1 plus some bug fixes
    [connector.sch, coordinator.kicad_pcb, coordinator.sch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]
2019-10-28 Complete driver layer.
2019-11-27 Version 2.0.1. Fixed Home-sensor connection bug
    [connector.sch, coordinator.kicad_pcb, coordinator.sch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]
2020-02-11 Finalized motor control to compensate drifts
    [coordinator_closeloop_main.c, coordinator_motor.c, motor.c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]
2020-09-01 Minor fixed in logging
    [coordinator_closeloop_main.c, demo.py, demo1.py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]
